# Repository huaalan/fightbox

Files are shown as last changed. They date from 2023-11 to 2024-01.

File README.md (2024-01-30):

# Fightbox
All button fightbox with 11 buttons

# Firmware
Use https://gp2040-ce.info/ to flash firmware
1. Download firmware. It is recommended to get the one for flatbox 5.
2. Flash the firmware, connect the board to a computer with a USB cable, then press the RESET button while holding the BOOT button on the RP2040-Zero. A drive named "RPI-RP2" should appear. Copy the UF2 file you downloaded to that drive.
3. Now that firmware has been flashed, use the built in web configurator to map buttons and configure controller (instructions at gp2040-ce.info)

# Troubleshooting
Start button bind missing?
If you used a firmware other than flatbox 5, try using the flatbox 5 since the pinouts for other firmware could be different.

Missing start button to get into web config after rebinding.
If you can't get the start bind back from flashing firmware, you will want to do a nuke flash and reflash the flatbox firmware so you will have the default buttons. The nuke flash will wipe all configurations.

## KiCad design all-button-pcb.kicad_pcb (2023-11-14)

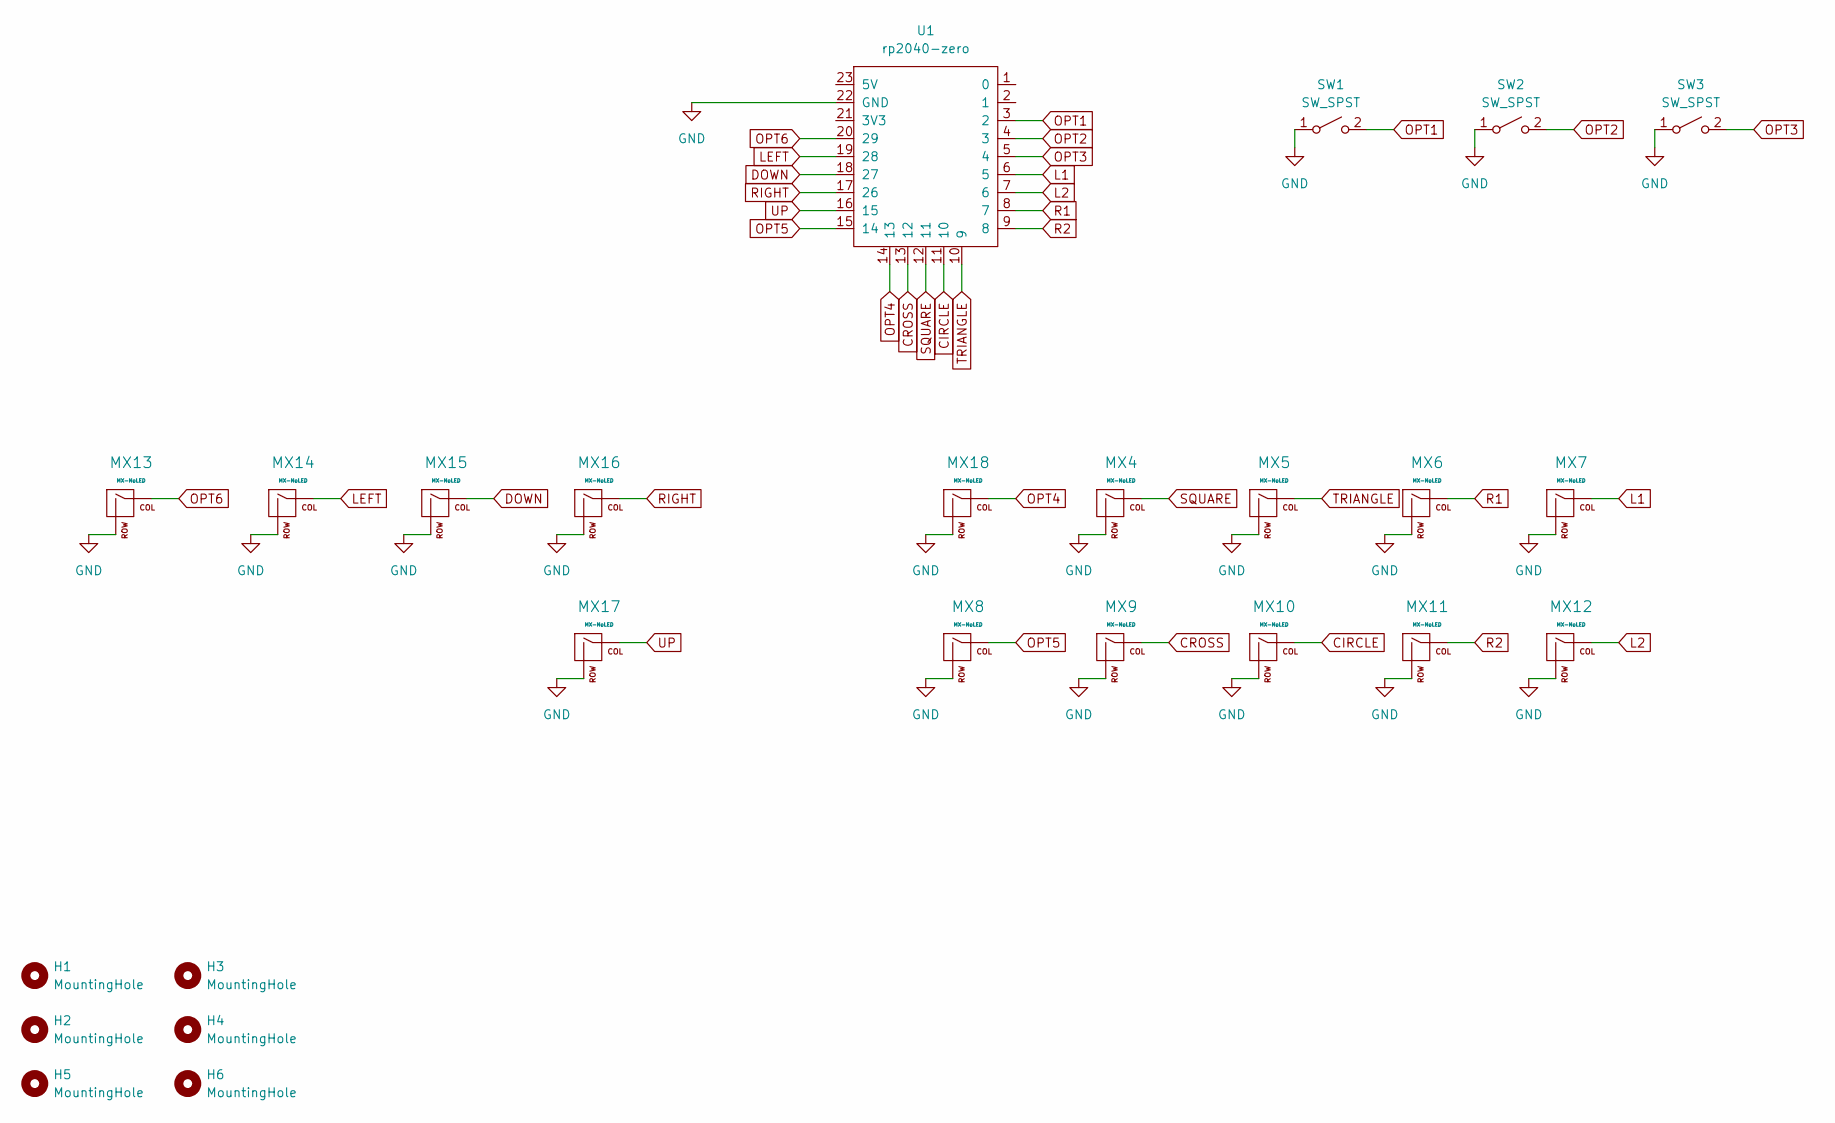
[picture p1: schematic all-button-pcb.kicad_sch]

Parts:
H1, H2, H3, H4, H5, H6: MountingHole; MountingHole_6.5mm
MX4, MX5, MX6, MX7, MX8, MX9, MX10, MX11, MX12, MX13, MX14, MX15, MX16, MX18: MX-NoLED; MX-Hotswap-1U-24mm
MX17: MX-NoLED; MX-Hotswap-1U-30mm
SW1, SW2, SW3: SW_SPST; SW_PUSH_6mm_H13mm
U1: rp2040-zero; RP2040-Zero

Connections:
CIRCLE: MX10.1 (COL), U1.11 (10)
CROSS: MX9.1 (COL), U1.13 (12)
DOWN: MX15.1 (COL), U1.18 (27)
GND: MX4.2 (ROW), MX5.2 (ROW), MX6.2 (ROW), MX7.2 (ROW), MX8.2 (ROW), MX9.2 (ROW), MX10.2 (ROW), MX11.2 (ROW), MX12.2 (ROW), MX13.2 (ROW), MX14.2 (ROW), MX15.2 (ROW), MX16.2 (ROW), MX17.2 (ROW), MX18.2 (ROW), SW1.1 (A), SW2.1 (A), SW3.1 (A), U1.22 (GND)
L1: MX7.1 (COL), U1.6 (5)
L2: MX12.1 (COL), U1.7 (6)
LEFT: MX14.1 (COL), U1.19 (28)
OPT1: SW1.2 (B), U1.3 (2)
OPT2: SW2.2 (B), U1.4 (3)
OPT3: SW3.2 (B), U1.5 (4)
OPT4: MX18.1 (COL), U1.14 (13)
OPT5: MX8.1 (COL), U1.15 (14)
OPT6: MX13.1 (COL), U1.20 (29)
R1: MX6.1 (COL), U1.8 (7)
R2: MX11.1 (COL), U1.9 (8)
RIGHT: MX16.1 (COL), U1.17 (26)
SQUARE: MX4.1 (COL), U1.12 (11)
TRIANGLE: MX5.1 (COL), U1.10 (9)
UP: MX17.1 (COL), U1.16 (15)

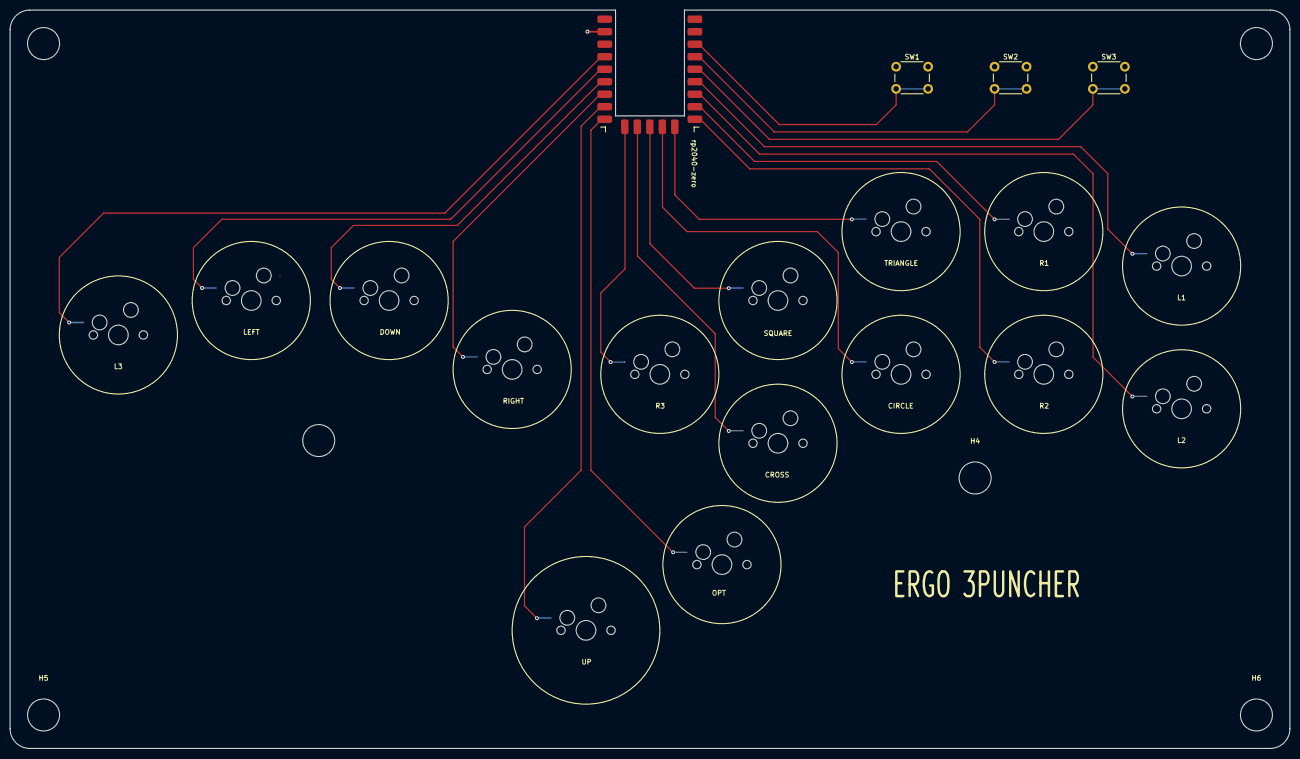
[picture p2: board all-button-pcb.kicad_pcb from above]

Board: 2 copper layers, 260.0 x 150.0 mm, 25 parts (0 on the bottom side), 19 nets.

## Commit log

2023-08-13 init
    initial files generated
    [all-button-pcb.kicad_pcb, all-button-pcb.kicad_sch]
2023-08-13 add submodules
    submodule footprint libraries for mx switches and other keyboard parts
2023-08-13 add footprint libraries
2023-08-14 add mcu library
    add symbol and footprint for rp2040 zero
2023-08-20 base design
    base design of schematics and pcb
    [all-button-pcb.kicad_pcb, all-button-pcb.kicad_sch]
2023-08-31 fix gnd pad placement
    gnd pad placement swap between 22 and 23
    [all-button-pcb.kicad_pcb]
2023-11-14 supportive holes
    added supportive holes for corners to trim case
    [all-button-pcb.kicad_pcb, all-button-pcb.kicad_sch, all-button-pcb_centered.kicad_pcb]
